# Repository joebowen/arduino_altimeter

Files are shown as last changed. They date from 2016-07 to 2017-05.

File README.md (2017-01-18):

# Flexible Field-Proof Arduino Model Rocket Altimeter (FFPAMRA)

The philosophy behind the FFPAMRA is to create an altimeter that is both flexible to the users' needs and still "field-proof".  The hobby of model rocketry is made up of very smart people, so they don't need things that are "idiot-proof".  But at the same time when working out at the field the more simple the steps to get an altimeter prepared, the less of a chance of making a simple mistake that can cause a rocket failure.  This is why the FFPAMRA is designed so that when in front of a computer the FFPAMRA can be fully programmed and modified, but at the field it's easy as turning it on and flying.  No more worrying about setting dip switches or counting beeps.

[Pictures, Data and BOM](https://drive.google.com/folderview?id=0B4IYU7UbyRPjVmt0ZWxkYTNBN1U&usp=sharing)

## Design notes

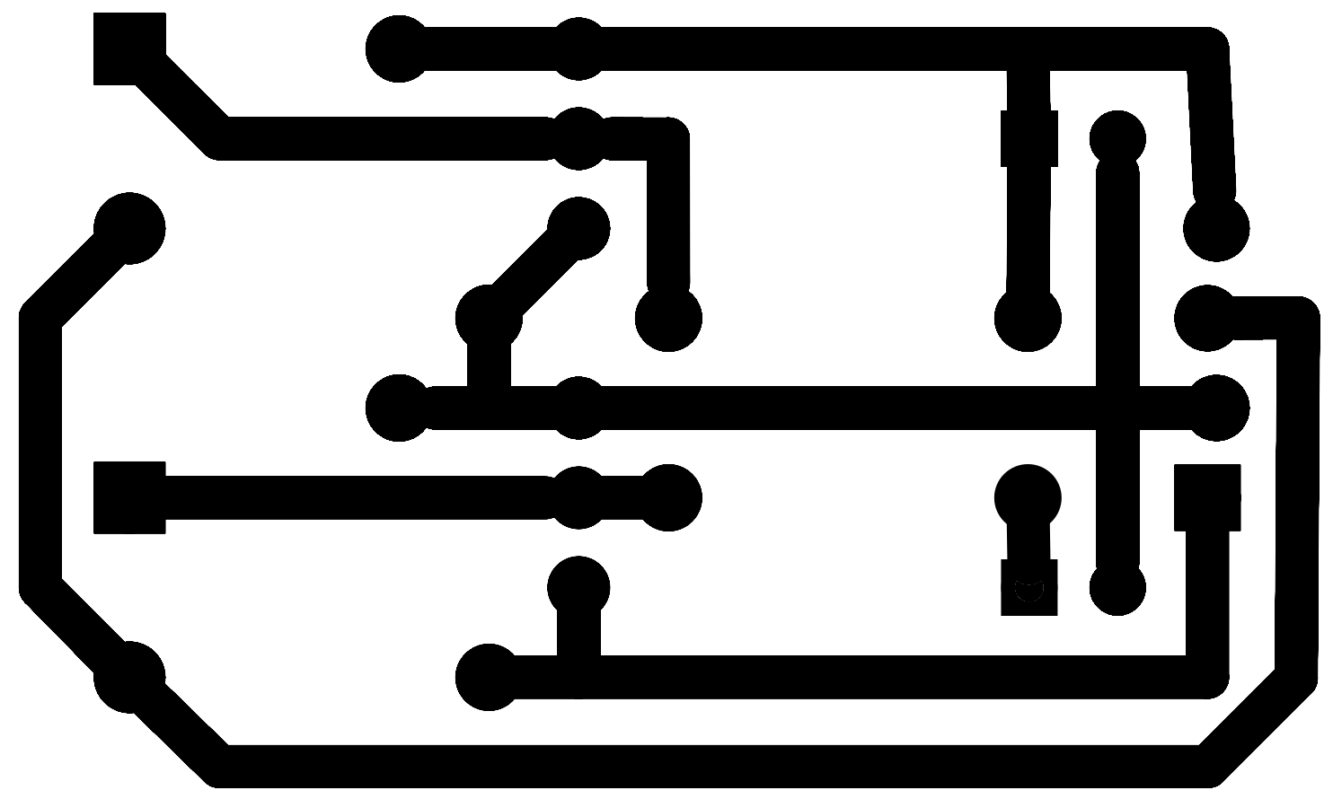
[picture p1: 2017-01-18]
Schematic&Boards/PyroCircuit/PyroCircuit_etch_copper_bottom.png

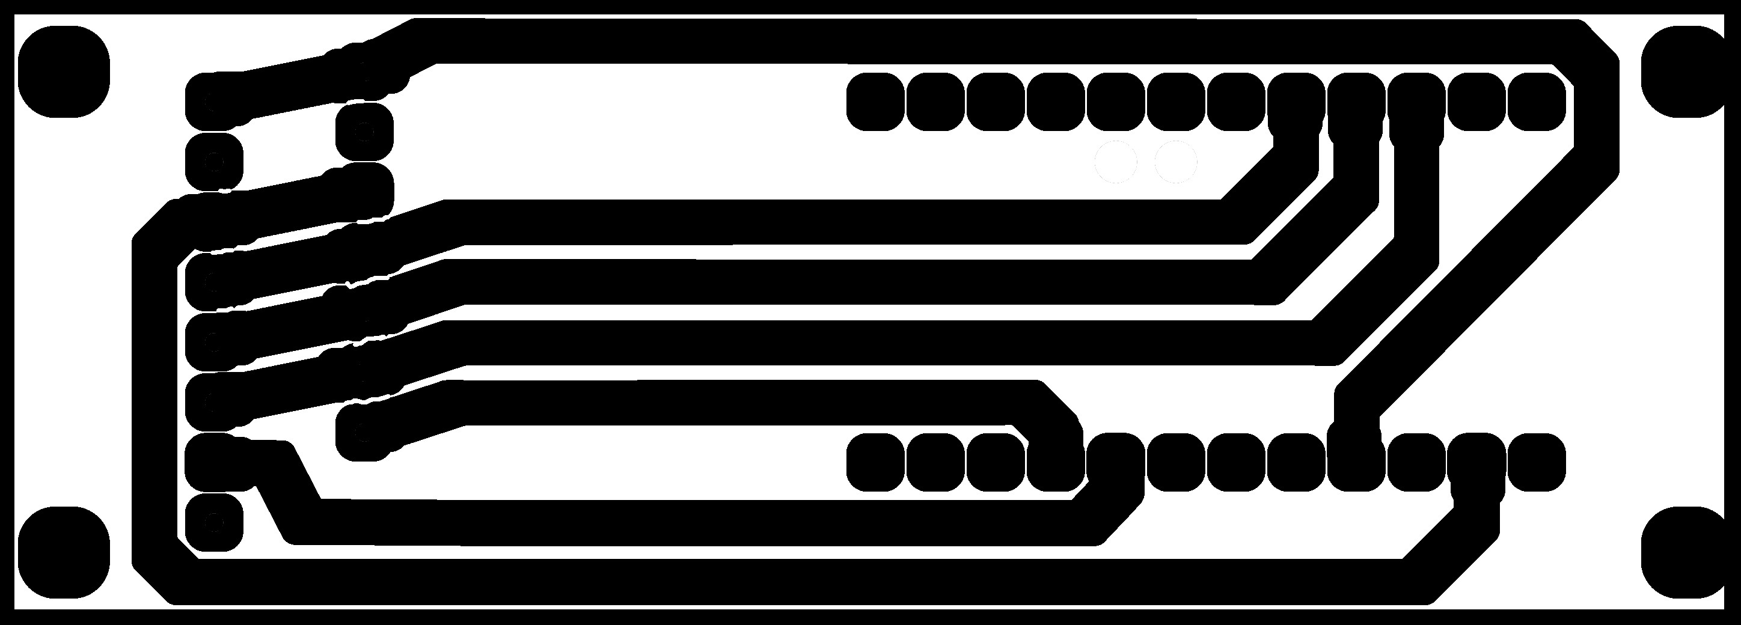
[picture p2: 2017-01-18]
Schematic&Boards/Altimeter-baro-only/Final/altimeter_baro_only_etch_copper_bottom-1.jpg

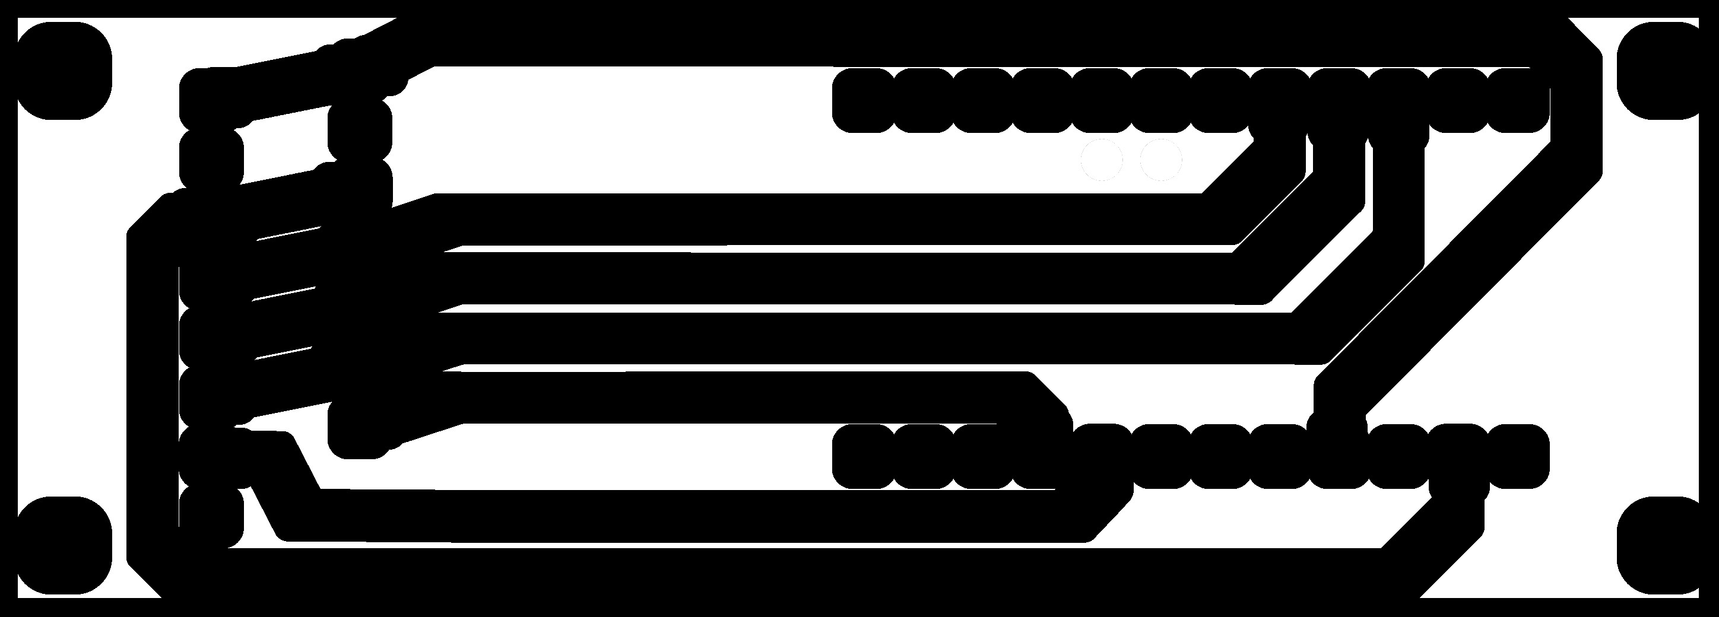
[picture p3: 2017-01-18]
Schematic&Boards/Altimeter-baro-only/Final/altimeter_baro_only_etch_copper_bottom-2.jpg

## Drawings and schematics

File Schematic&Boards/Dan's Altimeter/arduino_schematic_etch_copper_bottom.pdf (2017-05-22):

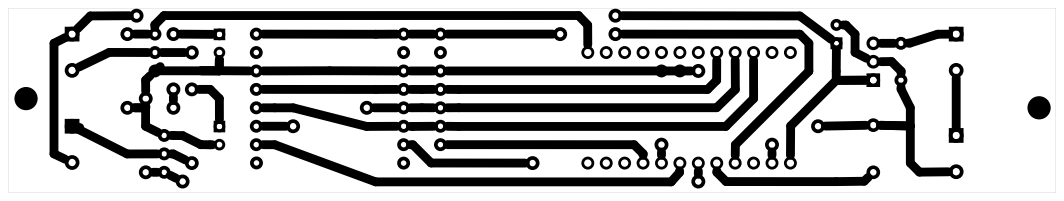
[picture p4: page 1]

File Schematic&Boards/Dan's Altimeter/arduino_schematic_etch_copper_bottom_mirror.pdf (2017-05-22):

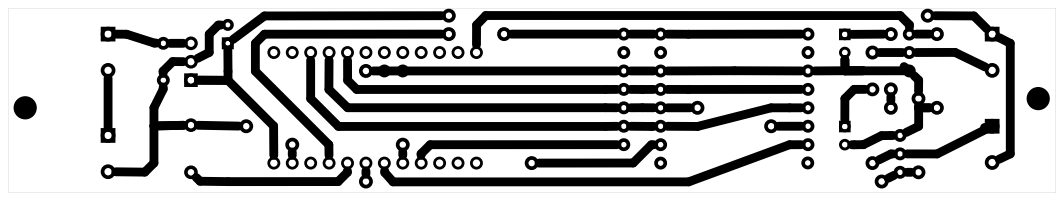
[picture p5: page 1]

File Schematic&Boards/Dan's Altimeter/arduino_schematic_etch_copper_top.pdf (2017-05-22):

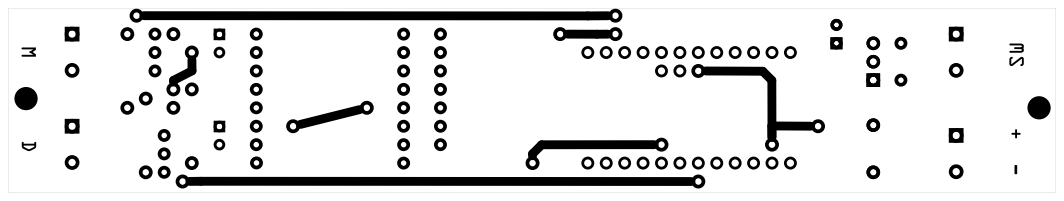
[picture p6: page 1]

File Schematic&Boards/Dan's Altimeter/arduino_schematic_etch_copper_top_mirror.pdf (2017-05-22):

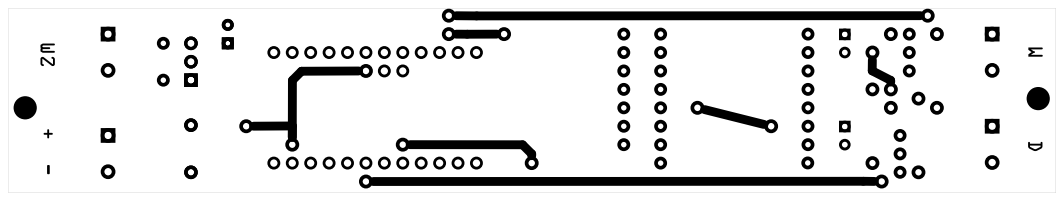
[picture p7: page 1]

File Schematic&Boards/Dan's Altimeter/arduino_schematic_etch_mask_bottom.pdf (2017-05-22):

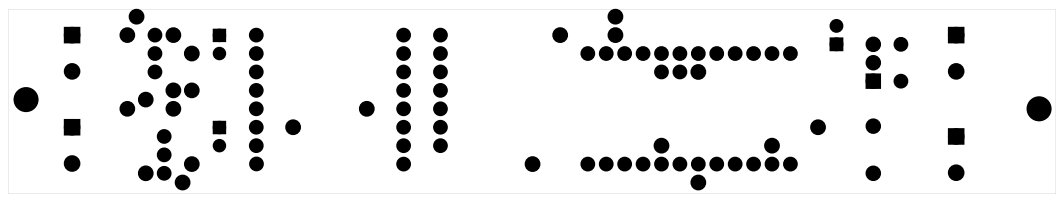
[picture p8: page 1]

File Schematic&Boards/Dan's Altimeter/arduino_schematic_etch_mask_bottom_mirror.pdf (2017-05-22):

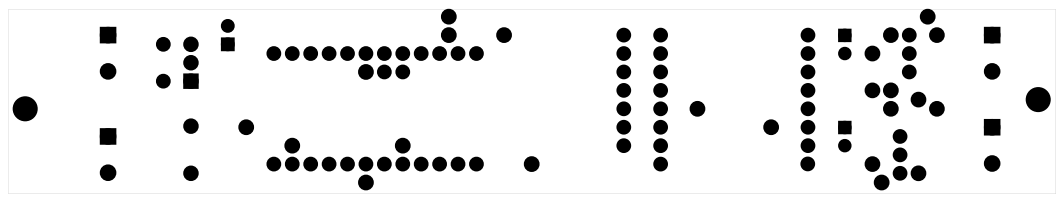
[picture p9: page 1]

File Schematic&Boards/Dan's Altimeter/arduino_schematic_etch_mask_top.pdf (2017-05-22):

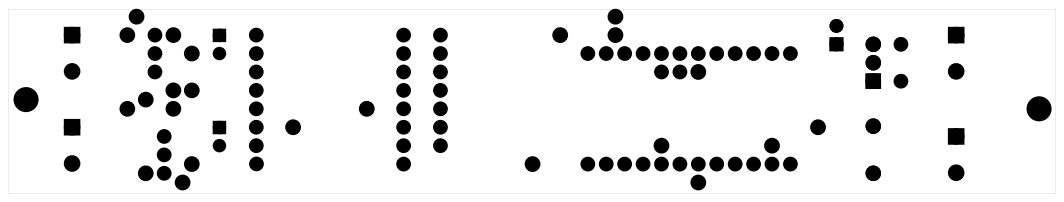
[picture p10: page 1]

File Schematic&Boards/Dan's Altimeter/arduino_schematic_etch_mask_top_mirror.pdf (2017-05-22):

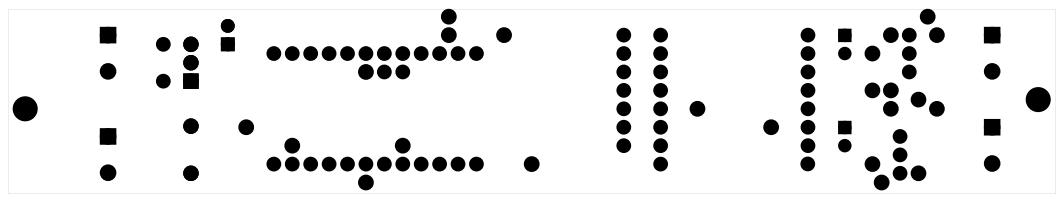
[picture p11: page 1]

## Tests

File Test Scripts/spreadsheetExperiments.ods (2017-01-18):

Smoothing | 0.1 | Adjustment Factors | -6.332185621 | -0.3135765615 | 0.7835259852
time(ms) | temperature(C) | pressure | absolute altitude(m)(probably wrong) | altitude(m) | raw velocity(m/s) | filtered velocity(m/s) | Raw X Accel(m/s^2) | Raw Y Accel(m/s^2) | Raw Z Accel(m/s^2) | Filtered x | Filtered y | Filtered z | Gravity adjusted x | Gravity adjusted y | Gravity adjusted z | Filtered and Gravity Adjusted x | Filtered and Gravity Adjusted y | Filtered and Gravity Adjusted z | Vector Accel(m/s^2) | x vel | y vel | z vel | Vector Vel | Vector Accel(m/s^2) | Est Alt(m) | Est Vel(m/s) | Est Accel(m/s^2) | Analog Raw X Accel | Analog Raw Y Accel | Analog Raw Z Accel
571842 | 30.07 | 82315 | 1718.622437 | 7.50061 | 0.869489 | 0.010811 | -6.282385 | -0.306458 | 0.766145 | -6.282385 | -0.306458 | 0.766145 | 0.049800621 | 0.0071185615 | -0.0173809852 | 0.049800621 | 0.0071185615 | -0.0173809852 | 0.7679585676 | 0 | 0 | 0 | 0 | 6.336344 | 7.153748 | 7.492352 | 6.298158 | 514 | 512 | 510
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

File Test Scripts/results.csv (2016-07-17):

Input noise values used (standard deviation):
#Altitude - 1.784931 meters
#Acceleration - 1.453188 meters/sec/sec
#Model noise - 0.207166 meters/sec/sec
#Kalman gains converged after 10 iterations.
0.393334 0.075479
0.276430 0.115630
0.146197 0.084673
#Estimated output first order statistics (standard deviation):
#Altitude - 1.119443 meters
#Velocity - 0.819773 meters/sec
#Acceleration - 0.431539 meters/sec/sec
# Output from rkal32:
# A third order Kalman filter using acceleration and pressure measurements
Time | Pressure Alt | Accel | Est Pos | Est Vel | Est Accel
0.000000 | 7.500610 | 0.036344 | 10.453595 | 2.077600 | 1.099648
0.414000 | 7.285889 | 0.061307 | 11.328130 | 2.480587 | 1.073447
0.821000 | 7.311523 | 0.112314 | 10.761296 | 1.678449 | 0.390958
1.228000 | 7.195435 | -0.020418 | 9.341463 | 0.262106 | -0.469441
1.628000 | 7.977783 | -0.009678 | 7.998159 | -0.949363 | -1.016794
2.035000 | 6.529785 | -0.191469 | 6.406181 | -2.134283 | -1.414300
2.443000 | 6.737427 | -0.025561 | 5.169183 | -2.820957 | -1.444485
2.859000 | 6.956909 | 5.673935 | 5.024372 | -2.169367 | -0.616891
3.265000 | 17.381104 | 51.122314 | 13.352502 | 7.386344 | 5.808275
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

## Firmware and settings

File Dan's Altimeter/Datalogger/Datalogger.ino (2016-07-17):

/*
  Flexible Field-Proof Arduino Model Rocket Altimeter

  Author: Joe Bowen
  Date: 12/18/15

  Resources used:
    - http://home.earthlink.net/~david.schultz/rnd/2004/KalmanApogeeII.pdf
    - Adafruit demo for LIS3DH
    - SD Card Datalogger example by Tom Igoe
    - bmp280test.ino
      - Written by Limor Fried & Kevin Townsend for Adafruit Industries.
*/

#include <SPI.h>
#include <Wire.h>
#include <Adafruit_Sensor.h>

#include <SD.h>               // SD Card module

#include <Adafruit_LIS3DH.h>  // LIS3DH Accel sensor
#include <Adafruit_BMP280.h>  // BMP280 Baro sensor

// Chip select pins for sensors and sd card.
#define BMP_CS 4              // Pin Number
#define SD_CS 5               // Pin Number
#define LIS3DH_CS 6           // Pin Number

// Buzzer pin
#define BUZZER_PIN 3          // Pin Number

// Pin numbers for pyro charges.
#define PYRO1 9               // Pin Number
#define PYRO2 10              // Pin Number

// Duration of pyro charge.
#define PYRO_DURATION 2000    // milliseconds

// Flight start detection settings.
// Values must be greater than all three settings
// to trigger flight start.
#define TRIGGER_ALT 10        // meters
#define TRIGGER_VEL 10        // meters/second
#define TRIGGER_TIME 500      // milliseconds

// Velocity limit to trigger apogee detection
#define APOGEE_VEL 10         // meters/second

// Main (pyro2) altitude limit
#define MAIN_ALT 150          // meters

// Flight end detection height
#define GROUND_ALT 25         // meters

// Set this to the maximum working altitude of the 
// baro sensor.
#define MAX_BARO_ALT 9000     // meters  

// Speed from the accelerometer above which locks 
// out deployment of drogue due to suspected mach effects.
#define MACH_LOCK 100         // meters/second

// Set these to enable/disable features.
// This is useful for reducing flash and ram 
// usage on smaller processors.
#define USE_SD false          // Use SD Card Module?
#define USE_LIS3DH true       // Use LIS3DH accel module?

// Accelerometer smoothing variable for the exponential decaying moving average.
#define SMOOTHING .02         

// Newline defaults
#define NEWLINE true
#define NONEWLINE false

// State machine states
#define S_INIT 0
#define S_FLIGHTSTARTED 1
#define S_WAITFORPYRO2 2
#define S_WAITFORGROUND 3
#define S_FINISHED 4

// Altimeter state variables
int state = S_INIT;           // Current state
unsigned long ts1;            // Milliseconds from first pyro
unsigned long ts2;            // Milliseconds from second pyro
bool fireEvent1 = false;      // First pyro event flag
bool fireEvent2 = false;      // Second pyro event flag
unsigned long flight_num = 0; // Flight Number
unsigned long prevMilli;      // Previous measurement time (milliseconds)
double prevAlt;               // Previous altitude measurement (meters)
double startAlt;              // Initial altitude measurement (meters)

double avgXaccel;             // Average X acceleration (m/s^2)
double avgYaccel;             // Average Y acceleration (m/s^2)
double avgZaccel;             // Average Z acceleration (m/s^2)      

double xAccelAdj = 0;         // Adjustment factor for gravity in the X axis
double yAccelAdj = 0;         // Adjustment factor for gravity in the Y axis
double zAccelAdj = 0;         // Adjustment factor for gravity in the Z axis

double xAccelVel = 0;         // X Velocity based on X Accelerometer (m/s)
double yAccelVel = 0;         // Y Velocity based on Y Accelerometer (m/s)
double zAccelVel = 0;         // Z Velocity based on Z Accelerometer (m/s)  

double prevXaccel = 0;        // Previous X acceleration value (m/s^2)
double prevYaccel = 0;        // Previous Y acceleration value (m/s^2)
double prevZaccel = 0;        // Previous Z acceleration value (m/s^2)

// Sensor Initalization
Adafruit_BMP280 bme(BMP_CS);
Adafruit_LIS3DH lis = Adafruit_LIS3DH(LIS3DH_CS);

void setup()
{
  // see if the SD card is present and can be initialized
  if (USE_SD) {
    if (!SD.begin(SD_CS)) {
      failure_mode("Write failure");
    }
  }
  
  find_flight_num();
  
  // see if the Baro/Temp sensor is present and can be initialized
  if (!bme.begin()) {
    failure_mode("BMP failure");
  }

  if (USE_LIS3DH) {
    // see if the Accelerometer sensor is present and can be initialized  
    if (!lis.begin(0x18)) {
      failure_mode("Accel failure");
    }
  
    // Inialize Accelerometer to +/-16G range
    lis.setRange(LIS3DH_RANGE_16_G); 
  }
  
  bool ret1 = write_to_sd("time(ms),temperature(C),pressure,absolute altitude(m)(probably wrong),altitude(m),raw velocity(m/s),", NONEWLINE);
  bool ret2 = write_to_sd("Raw X Accel(m/s^2),Raw Y Accel(m/s^2),Raw Z Accel(m/s^2),Vector Accel(m/s^2)", NEWLINE);

  if (!ret1 && !ret2)
  {
    failure_mode("Write failure");
  }
  
  // Need to first read temp and pressure to initialize readAltitude.
  bme.readTemperature();
  bme.readPressure();

  // Get initial altitude measurement.
  startAlt = bme.readAltitude(1013.25);
  prevAlt = startAlt;

  // Initialize clock.
  prevMilli = millis();

  // Initialize initial acceleration moving averages
  if (USE_LIS3DH) {
    sensors_event_t event; 
    lis.getEvent(&event);

    avgXaccel = event.acceleration.x;
    avgYaccel = event.acceleration.y;
    avgZaccel = event.acceleration.z;
  }
}

void loop()
{  
  double temp = bme.readTemperature();
  long int pressure = bme.readPressure();
  double rawAlt = bme.readAltitude(1013.25);
  
  unsigned long curMilli = millis();
  
  double rawVel = (rawAlt - prevAlt) / ((double)(curMilli - prevMilli) / 1000);
  
  double relAlt = rawAlt - startAlt;
  
  prevAlt = rawAlt;
  prevMilli = curMilli;
 
  write_to_sd(String(curMilli) + "," + String(temp) + ",", NONEWLINE);
  write_to_sd(String(pressure) + "," + String(rawAlt) + ",", NONEWLINE);
  write_to_sd(String(relAlt) + "," + String(rawVel) + ",", NONEWLINE);

  double vec_accel = 0;
  double vecAccelVel = 0;

  if (USE_LIS3DH) {
    sensors_event_t event; 
    lis.getEvent(&event);

    // Exponentially decaying moving average
    // The filter uses a fairly small SMOOTHING variable to allow the filter
    // to retain the average gravity a few cycles after launch when the launch code
    // finally detects a launch and saves these values to be used in offsets.
    avgXaccel = SMOOTHING * event.acceleration.x + (1.0 - SMOOTHING) * avgXaccel;
    avgYaccel = SMOOTHING * event.acceleration.y + (1.0 - SMOOTHING) * avgYaccel;
    avgZaccel = SMOOTHING * event.acceleration.z + (1.0 - SMOOTHING) * avgZaccel;

    write_to_sd(String(avgXaccel) + ",", NONEWLINE);
    write_to_sd(String(avgYaccel) + ",", NONEWLINE);
    write_to_sd(String(avgZaccel) + ",", NONEWLINE);
    
    write_to_sd(String(event.acceleration.x) + ",", NONEWLINE);
    write_to_sd(String(event.acceleration.y) + ",", NONEWLINE);
    write_to_sd(String(event.acceleration.z) + ",", NONEWLINE);
  
    vec_accel = abs_vector(event.acceleration.x - xAccelAdj, event.acceleration.y - yAccelAdj, event.acceleration.z - zAccelAdj);

    write_to_sd(String(vec_accel), NONEWLINE);

    // Integrate the accelerometer data to generate velocity values.
    xAccelVel = xAccelVel + (((double)(curMilli - prevMilli) / 1000) * (prevXaccel + event.acceleration.x - xAccelAdj) / 2);
    yAccelVel = yAccelVel + (((double)(curMilli - prevMilli) / 1000) * (prevYaccel + event.acceleration.y - yAccelAdj) / 2);
    zAccelVel = zAccelVel + (((double)(curMilli - prevMilli) / 1000) * (prevZaccel + event.acceleration.z - zAccelAdj) / 2);
    
    prevXaccel = event.acceleration.x - xAccelAdj;
    prevYaccel = event.acceleration.y - yAccelAdj;
    prevZaccel = event.acceleration.z - zAccelAdj;

    vecAccelVel = abs_vector(xAccelVel, yAccelVel, zAccelVel);

    write_to_sd(String(vecAccelVel), NEWLINE);
  }
  
  altimeter_state_tree(curMilli, vecAccelVel, rawVel, relAlt);

}

double abs_vector(double accel_x, double accel_y, double accel_z)
{
  return sqrt(pow(accel_x, 2) + pow(accel_y, 2) + pow(accel_z, 2));
}

int altimeter_state_tree(unsigned long time, double accelVel, double vel, double alt)
{
  switch (state)
  {
    case S_INIT:
      if (time > TRIGGER_TIME)
      {
        if (vel > TRIGGER_VEL)
        {
          if (alt > TRIGGER_ALT)
          {
            xAccelAdj = avgXaccel;
            yAccelAdj = avgYaccel;
            zAccelAdj = avgZaccel;
            
            state = S_FLIGHTSTARTED;
          }
        }
      }
      
      break;
    
    case S_FLIGHTSTARTED:
      if (vel < APOGEE_VEL && accelVel < MACH_LOCK)
      {
        fire_pyro(PYRO1);
        state = S_WAITFORPYRO2;
        ts1 = time;
        fireEvent1 = true;
      }
      
      break;
      
    case S_WAITFORPYRO2:
      if (alt < MAIN_ALT)
      {
        fire_pyro(PYRO2);
        state = S_WAITFORGROUND;
        ts2 = time;
        fireEvent2 = true;
      }
      
      break;
      
    case S_WAITFORGROUND:
      if (alt < GROUND_ALT)
      {
        state = S_FINISHED;
      }
      
      break;
      
    case S_FINISHED:
      failure_mode("Finished!");
           
      break;
  }
  
  check_pyro_event(time, PYRO1, ts1, fireEvent1);
  check_pyro_event(time, PYRO2, ts2, fireEvent2);
  
  return state;
}

void check_pyro_event(unsigned long time, int pyro_pin, unsigned long ts, bool event_flag)
{
  if ((time > ts + PYRO_DURATION) && event_flag)
  {
    turn_off_pyro(pyro_pin);
  }
}

void turn_off_pyro(int pyro_pin)
{
  pinMode(pyro_pin, OUTPUT);
  digitalWrite(pyro_pin, LOW);
}

void find_flight_num()
{
  flight_num = 1;
  if (USE_SD) {
    if (SD.exists("flights.txt")) {
      // Read flights.txt file and find last recorded flight number.
      File flights_read = SD.open("flights.txt");
      
      while (flights_read.available()) {
        char result[7]; 
        uint8_t i = 0; 
        
        char fileStr;
       
        fileStr = flights_read.read();
        
        while (fileStr != '\0' && i < sizeof(result) - 1) 
        {
          result[i] = fileStr;
          fileStr = flights_read.read();
          i++; 
        }
        
        result[i] = '\0';
        flight_num = atol(result) + 1;
      }
      flights_read.close();
      
      File flights_write = SD.open("flights.txt", FILE_WRITE | O_TRUNC);
      flights_write.println(String(flight_num));
      flights_write.close();
      
    } else {
      // Start new flights.txt file
      File flights = SD.open("flights.txt", FILE_WRITE);
      
      flights.println(flight_num);
      
      flights.close(); 
    }
  }
}

bool write_to_sd(String text, bool newLine)
{
  if (USE_SD) {
    // open the file. note that only one file can be open at a time,
    // so you have to close this one before opening another.
    String fileName = "flight" + String(flight_num) + ".csv";
    
    File dataFile = SD.open(fileName.c_str(), FILE_WRITE);
  
    // if the file is available, write to it:
    if (dataFile) 
    {
      if (newLine)
      {
        dataFile.println(text);
      }
      else
      {
        dataFile.print(text);
      }
      
      dataFile.flush();
      dataFile.close();
    }
    else
    {
      // return false on error
      return false;
    }
  }
  // return true on success
  return true;
}

void failure_mode(String errMsg)
{
  write_to_sd(errMsg, NEWLINE);
  
  analogWrite(BUZZER_PIN, 10); 
  
  turn_off_pyro(PYRO1);
  turn_off_pyro(PYRO2);
  
  while (1);
}

void fire_pyro(int pyro_ch)
{
  pinMode(pyro_ch, OUTPUT);
  digitalWrite(pyro_ch, HIGH);

  write_to_sd("Successful pyro.", NEWLINE);
}

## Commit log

2016-05-22 Initial commit.
    [arduino_schematic.fzz]
2016-07-17 Cleaned up project and updated dan's altimeter to use new algorithm
    [arduino_schematic.fzz, results.csv, spreadsheetExperiments.ods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]
2017-01-18 Reworked altimeter code to use headers for board settings. Fixed integrated accel calculation.
    [PyroCircuit.fzz, altimeter_baro_only.fzz, arduino_schematic.fzz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]
2017-05-22 Updated altimeters.
    [PyroCircuit.fzz, arduino_schematic.fzz, arduino_schematic_with_ADXL377.fzz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]
